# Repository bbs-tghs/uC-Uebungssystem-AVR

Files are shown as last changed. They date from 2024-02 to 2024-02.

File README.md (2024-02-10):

# uC-Übungssystem-AVR
Der erste selbst entwickelte Übungssystem für MikroController verwendet einen AVR, so wie er auch im Arduino zu finden ist.
Schaltplan und Layout wurden mit Eagle 5 erstellt. Die Bestückung ist nicht sonderlich schwierig. Industriell gefertigte Platinen mit Bestückungsdruck und Lötstoppmaske waren von Schülern ohne größere Schwierigkeiten aufzubauen.
Zur Programmierung haben wir AVR Studio zunächst in Version 6, spaäter dann in Version 7 verwendet. Damit als Basis sind einige schöne Projekte entstanden.

Der hier gezeigten Version gingen 5 Varianten voraus. Diese lassen wir hier weg.
Features_
  - 32 frei verwendbare Portpins
  - 4-stellige 7-Segment-Anzeige
  - 8 einzelne LEDs
  - 4 farbige Tasten
  - serieller Port zur Programmierung direkt aus AVR-Studio
  - Inkrementalgeber mit Pushbutton
  - Batteriegepufferte Echtzeituhr
  - EEPROM

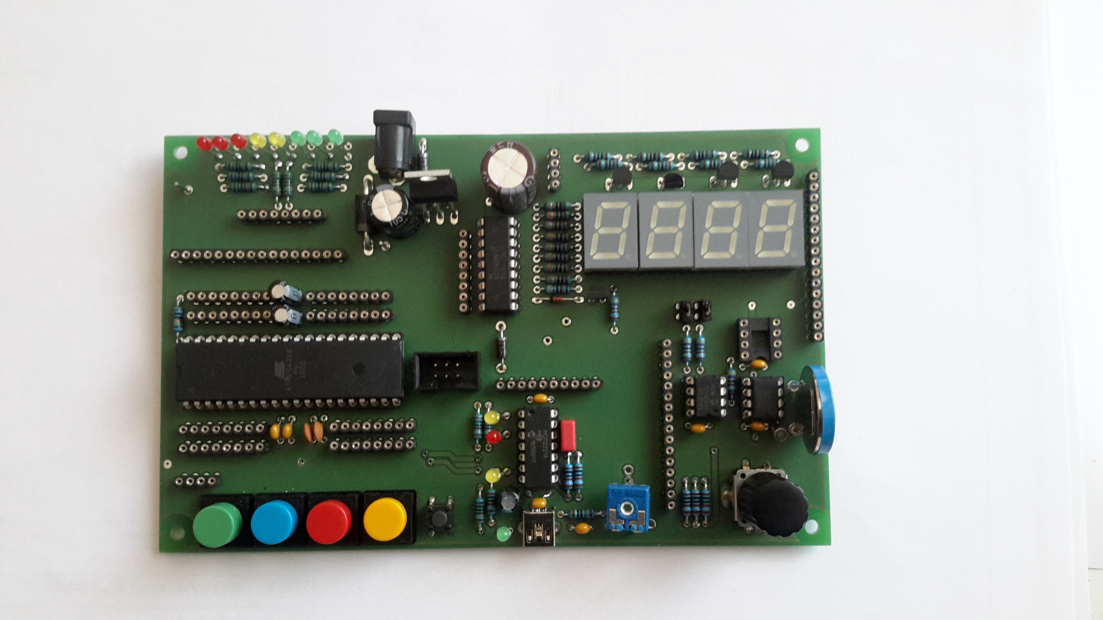
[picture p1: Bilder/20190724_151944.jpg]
So sieht das Ganze dann aus. Diese Platine noch ohne Bestückungsdruck Rev_6


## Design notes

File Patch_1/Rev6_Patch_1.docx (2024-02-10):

# Hardware-Patch des Übungssysrtem Rev. 6

Der Umbau erlaubt die Programmierung direkt aus Atml Studio heraus. Mit Hilfe einer kleinen Batch-Datei und einem neuen Bootloader im ATmega32 erfogt die Programmierung bzw. das Auslösen des Reset automatisch.

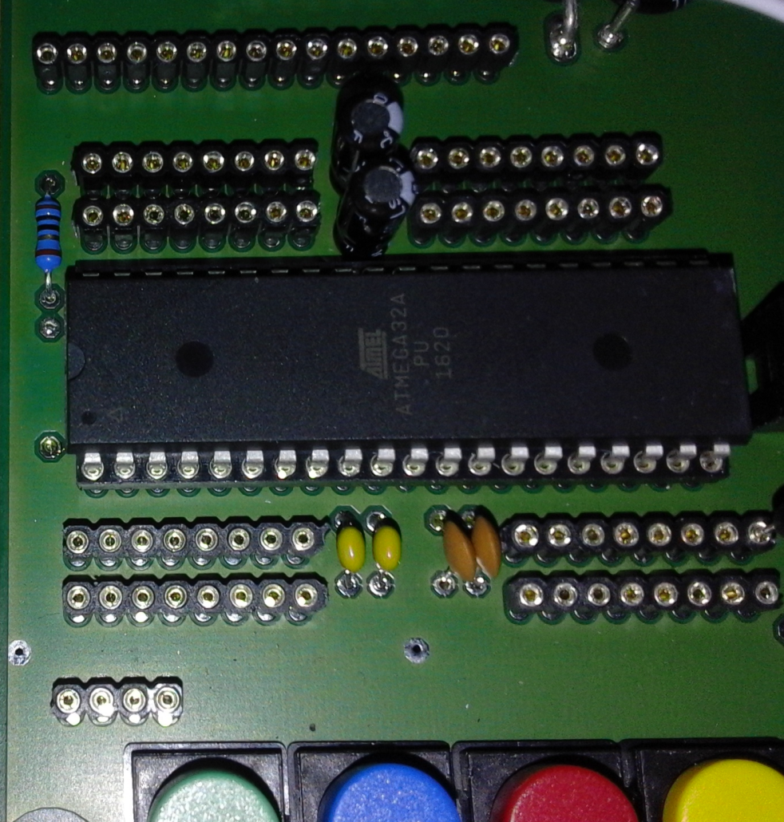
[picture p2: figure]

## Schritt 1:

R30 muss ausgelötet werden.

Der Widerstand bildet zusammen mit C7 das Netzwerk, welches den Reset auslöst

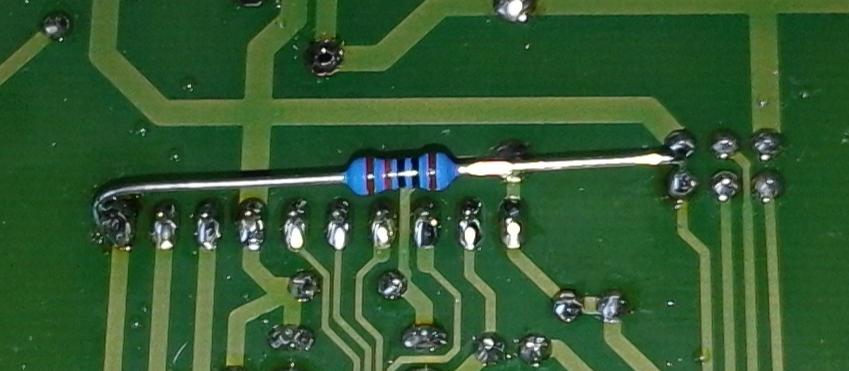
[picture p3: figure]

## Schritt 2:

Als Ersatz wird über einen 10k-Widerstand der Pin GP3 des Schnittstellenwandlers U3 mit der Reset-Leitung verbunden. Der Pin GP3 ist im Regelfall High, sodaß sich hier keine Änderung ergibt. Der Pin GP3 kann aber mit Hilfe eines Tools auf Low geschaltet werden, was einen Reset auslöst und den Bootloader startet.

Reset-Leitung am 6-pol. Programmiersockel SV10, Pin 5

GP3 an der 10-pol. Sockelleiste (SV4, Pin 10) des Schnittstellenbausteines

Zur Programmierung wird ADRDuve verwendet. Es ist im Order .\arduino_185 enthalten. Die Arduino-Die wir eigentlich nicht benötigt, es genügt AVRDude und die nachfolgenden Tools, welche direkt bei MicroChip heruntergeladen werden können.

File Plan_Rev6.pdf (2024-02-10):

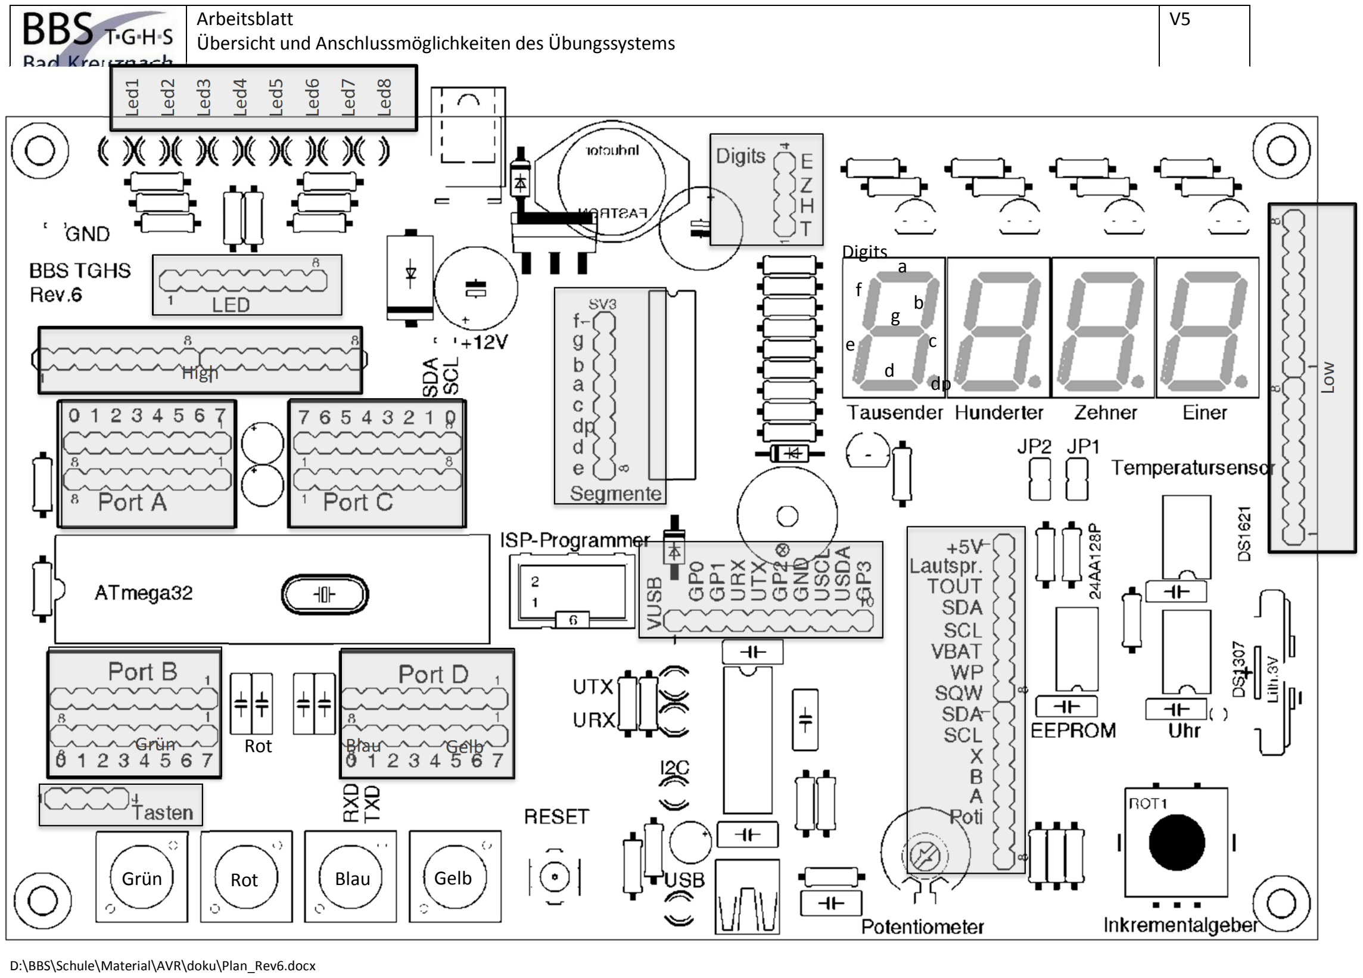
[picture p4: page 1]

Arbeitsblatt
Übersicht und Anschlussmöglichkeiten des Übungssystems

V5

D:\BBS\Schule\Material\AVR\doku\Plan_Rev6.docx

Low

Led1

Led2

Led3

Led4

Led5

Led6

Led7

Led8

Grün | Rot | Blau | Gelb

High

Digits
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
Grün | Rot | Blau | Gelb

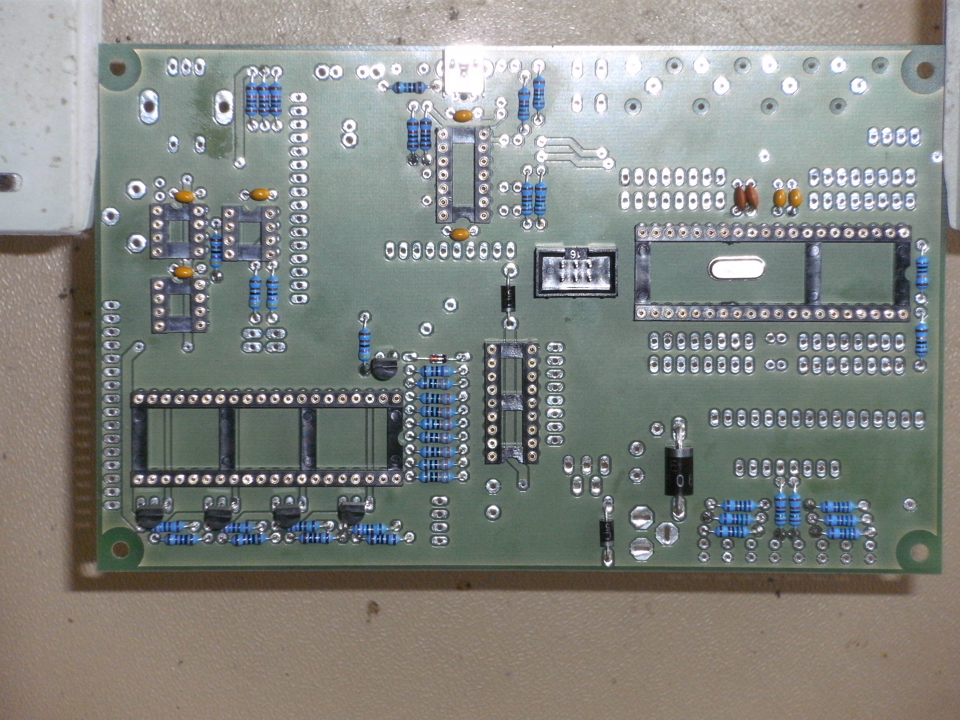
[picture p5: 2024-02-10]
Bilder/BILD1902.JPG

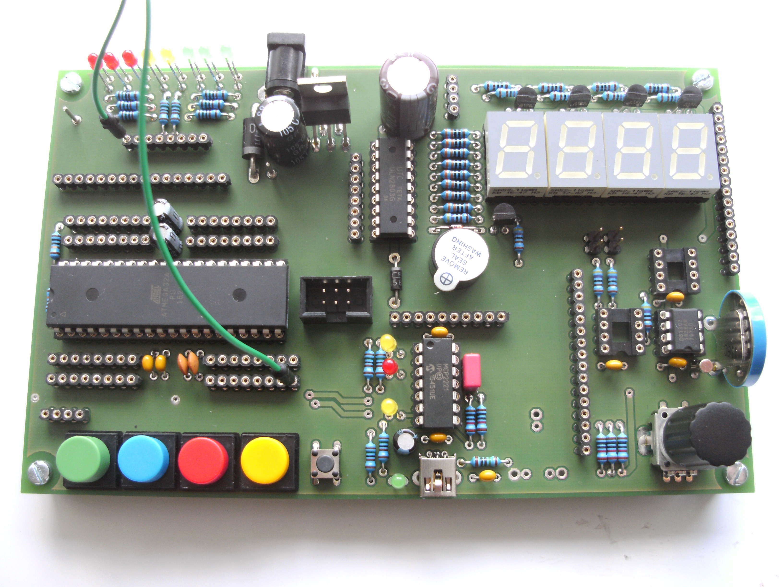
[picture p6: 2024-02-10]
Bilder/BILD1919.JPG

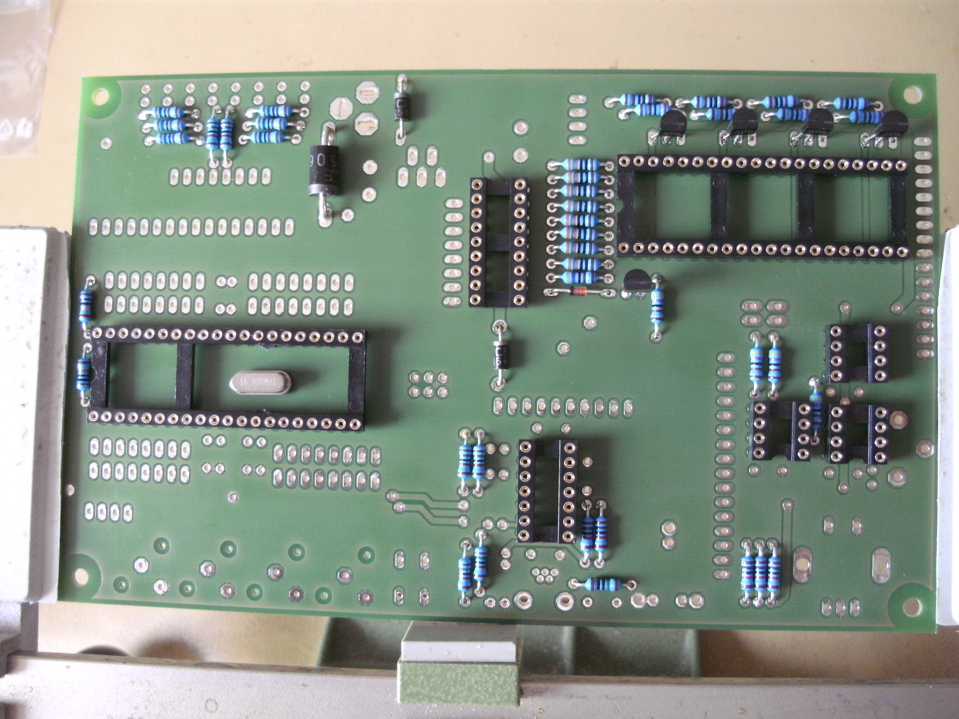
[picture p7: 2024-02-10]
Bilder/BILD1896.JPG

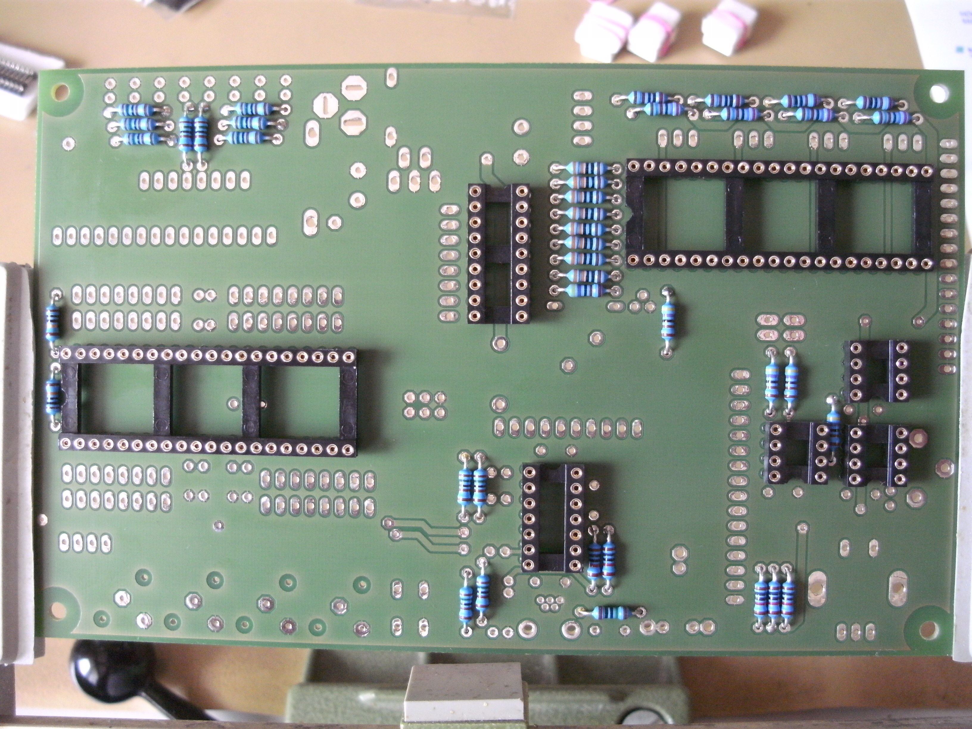
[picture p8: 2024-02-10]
Bilder/BILD1893.JPG

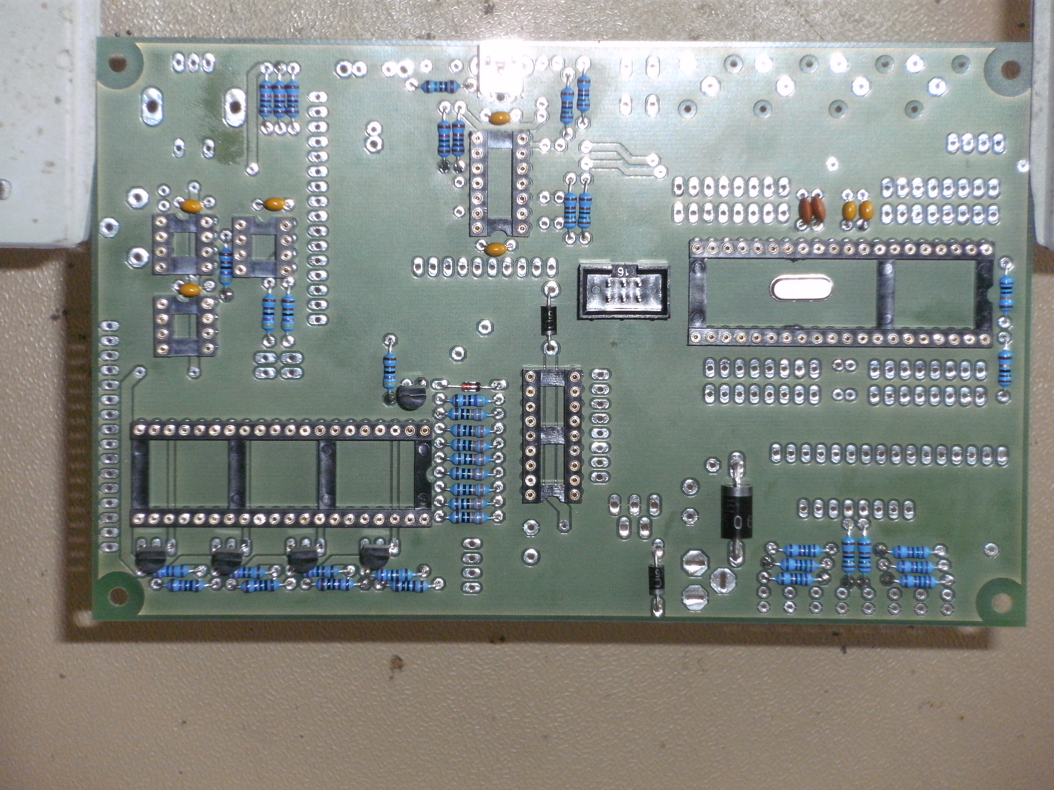
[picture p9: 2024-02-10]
Bilder/BILD1903.JPG

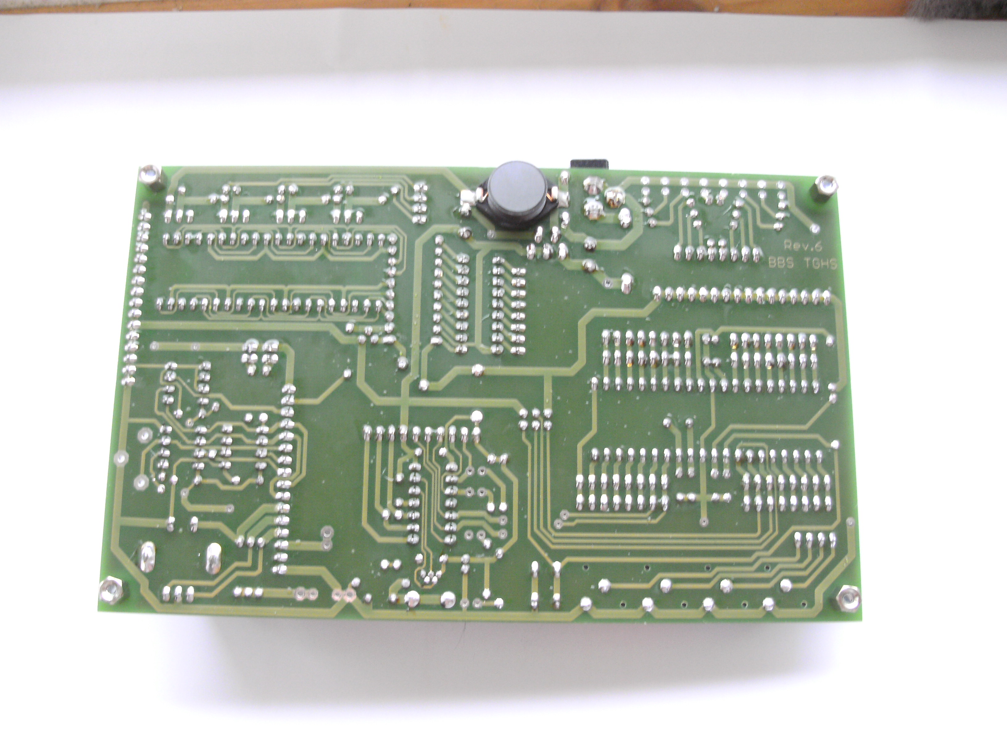
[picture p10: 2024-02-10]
Bilder/BILD1913.JPG

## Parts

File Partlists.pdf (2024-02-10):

## Teileliste für Übungsboard BBS TGHS Rev. 6

Ausstattung: Minimal
Stückzahl
Bauteil-Name | Bauteil | Größe | Anzahl | Best-Nr | E-Preis | G-Preis
C1 | 220uF/63V | RM5 / 10,5 | 1 | RAD 105 220/63 | 0,11 € | 0,11 €
C2 | 470uF/16V | RM5 / 10,5 | 1 | RAD 105 470/63 | 0,16 € | 0,16 €
C3,C4,C7,C8,C9,C15,C17 | 100nF | RM5 | 7 | X7R-5 100N | 0,04 € | 0,28 €
C5,C6 | 22pF | RM5 | 2 | KERKO 22P | 0,06 € | 0,12 €
C10, C11 | 4u7 / 16V | RM2,5 / 5 | 2 | RAD 105 4,7/100 | 0,04 € | 0,08 €
C12 | 47µF / 25V | RM2 / 5 | 1 | RAD 105 47/35 | 0,04 € | 0,04 €
C14 | 330nF | RM5 | 1 | MKS2-50 330N | 0,19 € | 0,19 €
C16 | 10nF | RM5 | 1 | X7R-5 10N | 0,05 € | 0,05 €
D1 | SB560 | | 1 | SB 560 | 0,26 € | 0,26 €
D2, D4 | 1N5819S | | 2 | 1N 5819 | 0,06 € | 0,12 €
D3 | 1N4148 | | 1 | 1N 4148 | 0,04 € | 0,04 €
DL1,DL2,DL3,DL4 | D350PA | | 4 | SA 52-11 GN | 0,71 € | 2,84 €
G1 | CR2032V | | 1 | CR 2032P-V | 1,15 € | 1,15 €
IC1 | ULN2803 | | 1 | ULN 2803A | 0,34 € | 0,34 €
IC2 | DS1621 | | 1 | | | - €
IC3 | 24AA128P | | 1 | 24AA128-I/P | 0,86 € | 0,86 €
IC4 | MEGA32-P | | 1 | ATMEGA 32A-PU | 4,60 € | 4,60 €
J1 | JACK-PLUG1 | | 1 | HEBW 21 | 0,26 € | 0,26 €
LED1..LED3,LED,LED11 | LED 3mm Low current | rot | 4 | LED 3MM 2MA RT | 0,09 € | 0,36 €
LED4, LED5,LED10,LED12 | LED 3mm Low current | gelb | 4 | LED 3MM 2MA GE | 0,10 € | 0,40 €
LED6..LED9 | LED 3mm Low current | grün | 4 | LED 3MM 2MA GN | 0,09 € | 0,36 €
Q1,Q2,Q3,Q4 | BC327-40 | | 4 | BC 327-40 | 0,04 € | 0,16 €
Q5 | BC337-40 | | 1 | BC 337-40 | 0,04 € | 0,04 €
Q6 | Quarz 16MHz | | 1 | 16,0000-HC49U-S | 0,28 € | 0,28 €
Q7 | Quarz | 32,768kHz | 1 | 0,032768 | 0,20 € | 0,20 €
U1 | Step-Down-U-Regl. | | 1 | LM 2575 T5,0 | 1,25 € | 1,25 €
U2 | DS1307P | | 1 | DS 1307 | 2,80 € | 2,80 €
U3 | MCP2221 | | 1 | MCP 2221-I/P | 2,60 € | 2,60 €
R1,R2,R3,R4 | 2,7k | Metall | 4 | METALL 2,70k | 0,08 € | 0,33 €
R5, R6, R7, R8 | 1k | Metall | 4 | METALL 1,00 k | 0,08 € | 0,33 €
R9, R10, R11, R12, R13,
R14, R15, R16, R37, R38,
R39, R40 | 1,5k | Metall | 12 | METALL 1,50 k | 0,08 € | 0,98 €
R17, R18, R19, R20, R21,
R22, R23, R24 | 330R | Metall | 8 | METALL 330 | 0,08 € | 0,64 €
R25 | Poti | | 1 | ACP 9-LRS 10k | 0,25 € | 0,25 €
R26,R27, R28, R29, R32 | 4,7k | Metall | 5 | METALL 4,70k | 0,08 € | 0,40 €
R33, R34, R35, R41, R42 | 10k | Metall | 5 | METALL 10,0k | 0,08 € | 0,40 €
R30 | 100k | Metall | 1 | METALL 100k | 0,08 € | 0,08 €
R31 | 10 Ohm | Metall | 1 | METALL 10,0 | 0,08 € | 0,08 €
R36 | 10M | Metall | 1 | METALL 10,0M | 0,08 € | 0,08 €
S1 | Taster | | 1 | TASTER 3301 | 0,12 € | 0,12 €
S2 | Taster | grün | 1 | TASTER 1032.5 | 1,25 € | 1,25 €
S3 | Taster | blau | 1 | TASTER 1032.4 | 1,20 € | 1,20 €
S4 | Taster | rot | 1 | TASTER 1032.3 | 1,20 € | 1,20 €
S5 | Taster | gelb | 1 | TASTER 1032.1 | 1,20 € | 1,20 €
ROT1 | Inkrementalgeber | | 1 | STEC12E08 | 1,90 € | 1,90 €
SP1 | magn. Tongeber | RM 6,5mm | 1 | SUMMER AL-60P12 | 0,55 € | 0,55 €
SV10 | Wannenstecker | 6-pol. | 1 | WSL 6G | 0,16 € | 0,16 €
SV1..SV8, SV11..SV21 | Sockelleiste | 32-pol | 5 | SPL 32 | 0,56 € | 2,80 €
L1 | Spule | 100uH | 1 | L-PISR 100µ | 0,88 € | 0,88 €
JP1, JP2 | Jumper | 2 pol | 2 | MPE 087-1-002 | 0,05 € | 0,10 €
| Steckachse für Poti | | 1 | ACHSE ACP 9 S | 0,07 € | 0,07 €
| Knopf für Poti | | 1 | KNOPF 13-164B | 0,46 € | 0,46 €
| Knopf für Inkrementalgeber | | 1 | KNOPF 13-164E | 0,46 € | 0,46 €
| IC-Sockel | DIL40 | 2 | GS 40P | 0,62 € | 1,24 €
| IC-Sockel | DIL18 | 1 | GS 18P | 0,32 € | 0,32 €
| IC-Sockel | DIL14 | 1 | GS 14P | 0,23 € | 0,23 €
| IC-Sockel | DIL8 | 3 | GS 8P | 0,19 € | 0,57 €
USB | Mini-USB-Buchse | Print | 1 | USB BWM | 0,51 € | 0,51 €
| Stehbolzen | 5mm | 4 | DI 5MM | 0,08 € | 0,32 €
- €
| Summe | | 87 | | | 34,77 €
| Gesamt (alles): | 34,77 €

### Reichelt

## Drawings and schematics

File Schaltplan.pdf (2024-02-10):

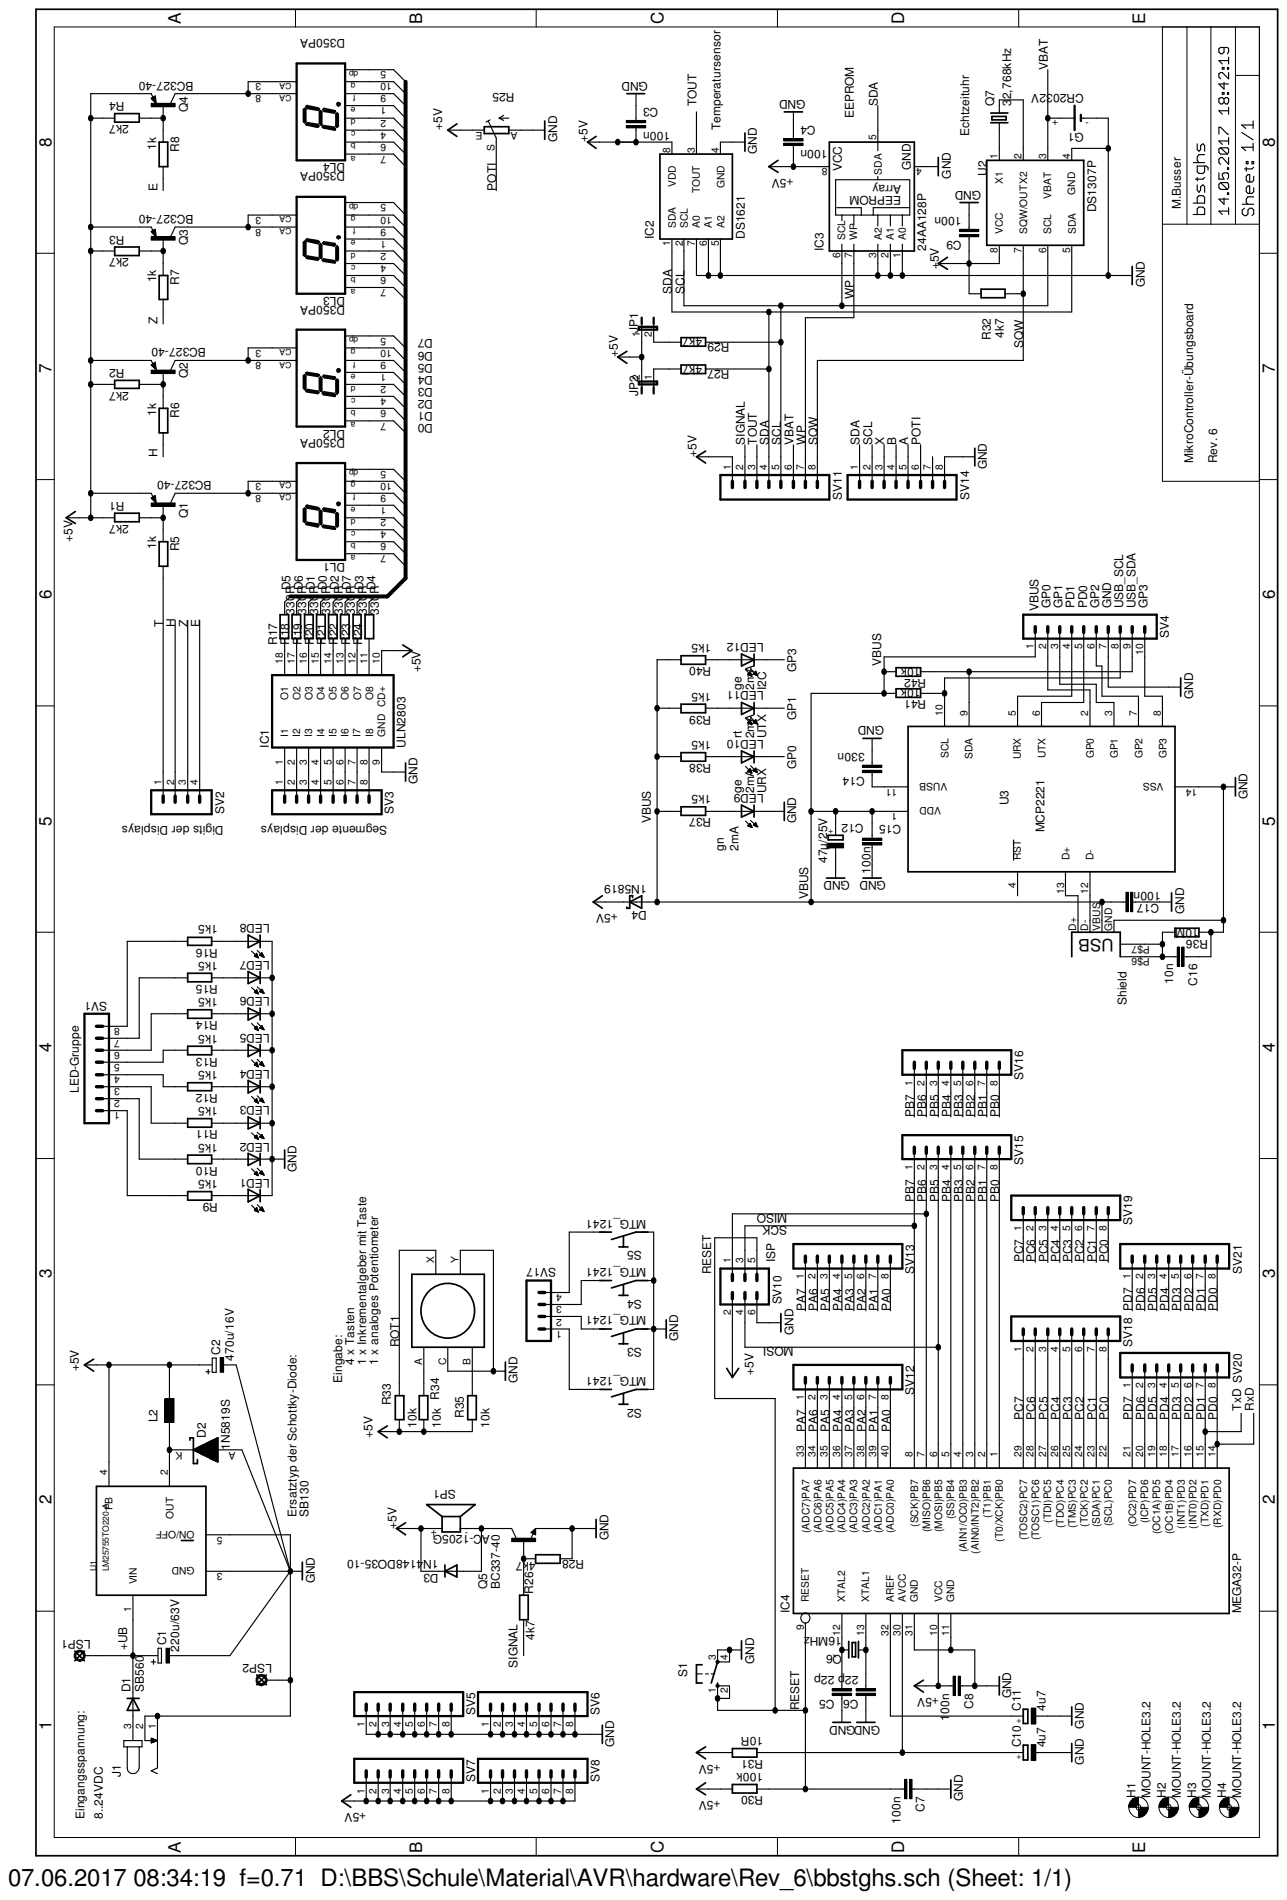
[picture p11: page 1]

Ersatztyp der Schottky-Diode:

07.06.2017 08:34:19 f=0.71 D:\BBS\Schule\Material\AVR\hardware\Rev_6\bbstghs.sch (Sheet: 1/1)

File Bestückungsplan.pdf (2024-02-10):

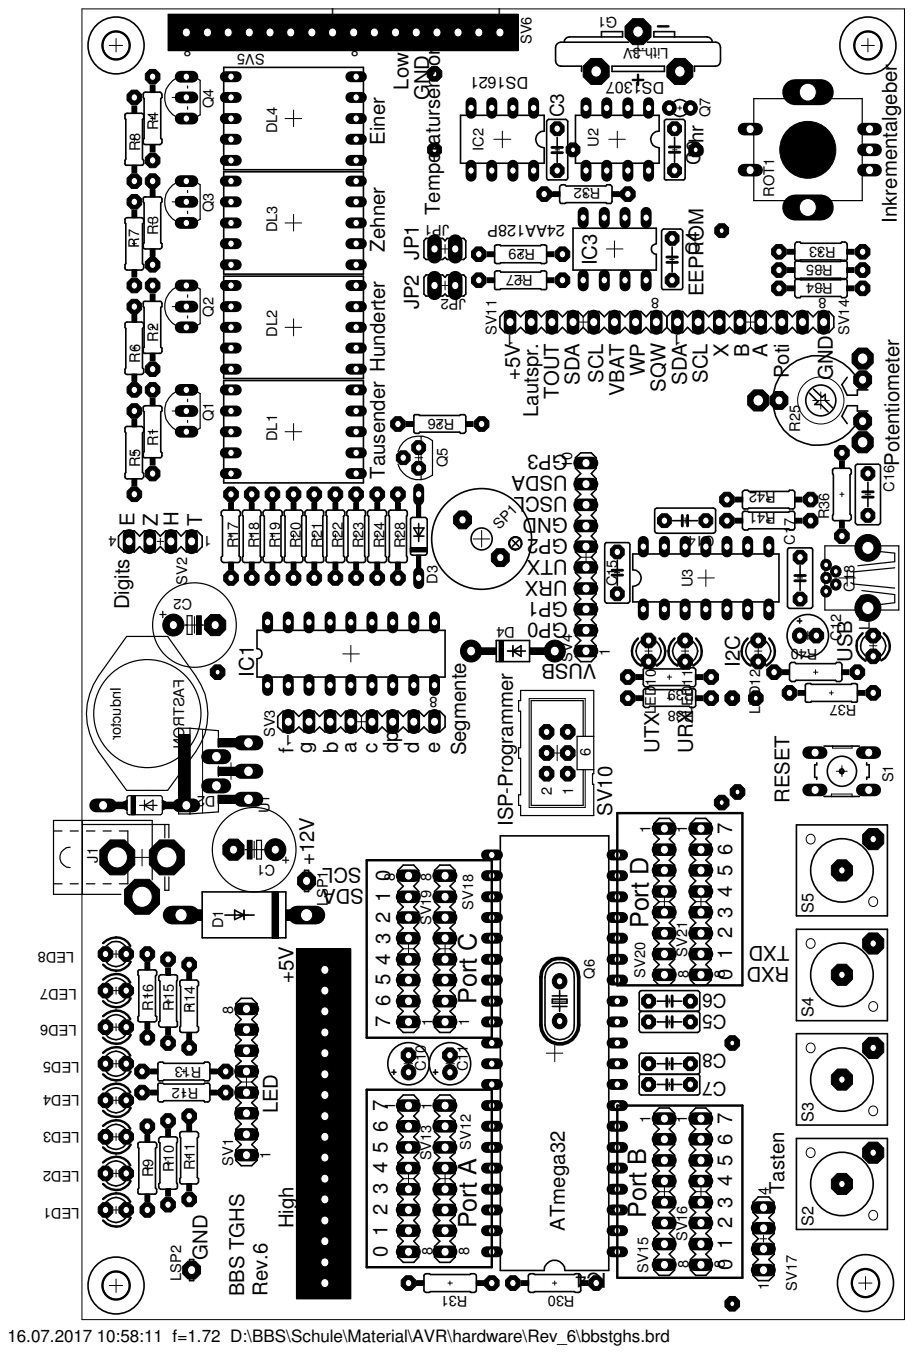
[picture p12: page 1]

Einer Zehner Hunderter Tausender
